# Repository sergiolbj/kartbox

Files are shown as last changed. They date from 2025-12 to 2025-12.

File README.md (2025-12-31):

# 🏎️ KartBox - Telemetria Avançada para Karting (ESP32)

O **KartBox** é um sistema de telemetria e dashboard para Karts de competição, desenvolvido com **ESP32** (ESP-IDF) e **LVGL v9**. Ele oferece monitoramento em tempo real de tempos de volta, velocidade, delta (gap) e registro de dados em cartão SD para análise posterior.






## 📸 Screenshots

*(Espaço reservado para você colocar uma foto ou print da tela do seu projeto)*

## 🚀 Funcionalidades Principais

### 🏁 Dashboard de Corrida (Aba Race)
- **Velocidade em Tempo Real:** Leitura de GPS de alta precisão.
- **Lap Timer:** Tempo da volta atual, última volta e **Best Lap**.
- **Live Delta:** Mostra a diferença de tempo para a melhor volta em tempo real (Verde = Mais rápido, Vermelho = Mais lento).
- **Modos de Corrida:** Alternância entre *Qualy* (Classificação) e *Race* (Corrida).

### 📊 Análise de Dados (Aba Voltas)
- **Histórico de Sessões:** Lista corridas salvas no SD pelo nome do arquivo (ex: `SESSION_001.LOG`).
- **Gráfico Dinâmico:**
  - Eixo Y (Velocidade) escala automaticamente conforme a maior velocidade atingida.
  - Eixo X exibe o número das voltas.
- **Botão Refresh:** Recarrega os dados do cartão SD sem reiniciar o sistema.

### 💾 Datalogger Robusto (SD Card)
- **Arquitetura Anti-Crash:** O salvamento de arquivos pesados roda em uma **Task FreeRTOS dedicada**, isolada da interface gráfica (UI), prevenindo erros de *Spinlock* e travamentos visuais.
- **CSV Format:** Dados exportáveis (Lat, Lon, Speed, Timestamp) compatíveis com softwares de análise.
- **Detecção Inteligente:** Identifica arquivos automaticamente na inicialização.

### 🛰️ Monitoramento de Saúde do GPS
Diagnóstico visual avançado no topo da tela:
- 🔴 **GPS: ERRO HW:** Módulo desconectado ou falha de comunicação (RX/TX).
- 🟡 **SATS: 0 BUSCA...:** Hardware OK, aguardando sinal de satélites.
- 🟢 **SATS: X FIX:** Sinal travado e pronto para uso.

## 🛠️ Hardware Utilizado

- **MCU:** ESP32-P4 (Function EV Board) ou compatível (ESP32-S3/WROOM).
- **Display:** LCD com interface RGB/SPI (Driver ST7701/EK79007).
- **GPS:** Módulo NMEA (ex: BN-880, NEO-6M) via UART.
- **Armazenamento:** Módulo MicroSD (SDMMC ou SPI).
- **IMU:** (Opcional) MPU6050/9250 para dados de força G.

## 📂 Estrutura do Projeto

```text
/main
├── main.c              # Ponto de entrada e setup do hardware
├── ui_kartbox.c        # Lógica da Interface (LVGL), Gráficos e Eventos
├── telemetry_gps.c     # Parser NMEA e lógica de Delta
├── telemetry_sd.c      # Gerenciamento de Arquivos e Logs
├── telemetry_mpu.c     # Leitura de sensores inerciais
└── ...

🎮 Como Usar
Inicialização: Ao ligar, aguarde o status do GPS ficar VERDE (FIX).

Marcar Linha de Chegada: Na primeira volta, pressione "MARCAR" onde deseja definir a linha de chegada/largada.

Correr: O sistema detectará as voltas automaticamente via coordenadas GPS.

Salvar: Ao fim da corrida, segure o botão "RESET" por 2 segundos.

Nota: O salvamento ocorre em background. Uma barra de progresso indicará a conclusão.

Revisar: Vá até a aba "VOLTAS", selecione a corrida e clique no botão de Refresh 🔄 para ver o gráfico de desempenho.

🤝 Contribuição
Contribuições são bem-vindas! Sinta-se à vontade para abrir Issues ou enviar Pull Requests.

📜 Licença
Este projeto está sob a licença MIT. Sinta-se livre para usar e modificar.

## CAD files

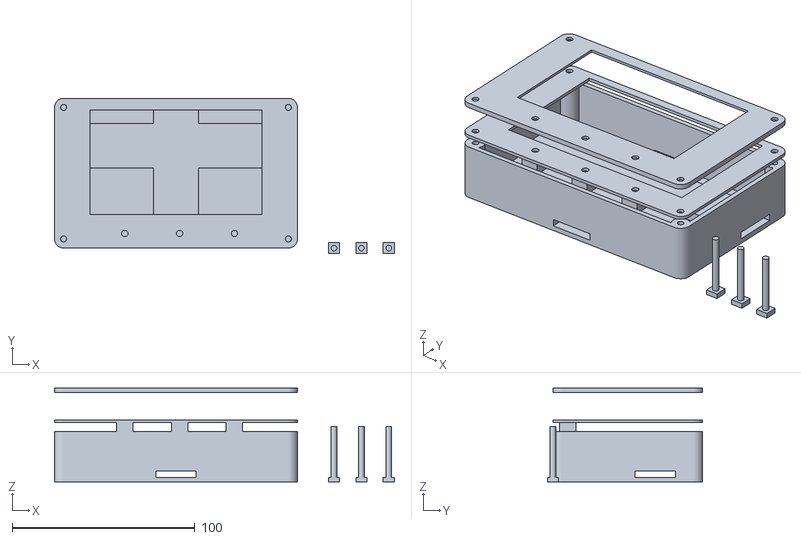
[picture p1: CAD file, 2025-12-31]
Case/kartbox_case_v4.stl
186.1 x 85.1 x 51.4

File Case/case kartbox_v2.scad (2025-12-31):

// ==========================================
//   KARTBOX PRO - BOTÕES COM ENCAIXE QUADRADO
// ==========================================

// --- 1. DIMENSÕES TÉCNICAS (LCD 4.3") ---
tela_l = 104; 
tela_c = 62.0;
margem_parafuso = 12.0;      
espaco_botoes = 15.0;       
gap_topo_tela = 2.0;        
deslocamento_geral_x = 2.0; 
distancia_entre_botoes = 30.0; 

// AJUSTE: Offset exclusivo para a peça do meio (suporte da tela)
offset_x_tampa_meio = 0.0; 

// AJUSTE: Offset vertical dos botões
offset_y_botoes = -2.0; 

// --- 2. CONFIGURAÇÃO DO BERÇO E DO PINO (ANTI-ROTAÇÃO) ---
dim_switch = 6.6;           // Encaixe interno do berço
parede_berco = 1.2;         
altura_parede_berco = 8.0;  // Profundidade do guia do botão

// Configuração do Botão (Pino)
dim_base_pino = dim_switch - 0.4; // Folga de 0.2mm de cada lado para deslizar
altura_base_pino = 2.5;           // Altura da parte quadrada que impede a rotação

// --- 3. CONFIGURAÇÃO DA MOLDURA SUPERIOR (A CASCA) ---
espessura_teto_moldura = 1.2;   
espessura_parede_moldura = 2; 
altura_interna_moldura = 1.2;   

// --- 4. AJUSTE DO VISOR (MOLDURA SUPERIOR) ---
moldura_janela_l = 94.0;    
moldura_janela_c = 57.0;    
moldura_h_offset = 0.0;     
moldura_v_offset = 6.5;     

// --- 5. ESTRUTURA DA BASE E TAMPA DO MEIO ---
espessura_tampa_meio = 1.5;      
altura_interna_base = 25.0; 
espessura_parede_caixa = 2.5;     
altura_strap = 3.5;         
parede_blindagem = 1.2;     

// --- 6. HARDWARE E CINTAS ---
btn_furo_diam = 3.5;        
diam_furo_m3 = 3.4;         
diam_insercao_m3 = 4.0;     
prof_insercao_m3 = 6.0;     
pos_strap_horizontal = 15;   
largura_strap = 22.0;       

// ==========================================
//   CÁLCULOS AUTOMÁTICOS
// ==========================================
largura = tela_l + (espessura_parede_caixa * 2) + (margem_parafuso * 2);
comprimento = tela_c + espaco_botoes + (espessura_parede_caixa * 2); 
altura_total_base = altura_interna_base + espessura_parede_caixa;
espessura_total_moldura = altura_interna_moldura + espessura_teto_moldura;
raio_canto = 5;
$fn = 60;

pos_x_parafuso = [raio_canto, largura - raio_canto];
pos_y_parafuso = [raio_canto, comprimento - raio_canto];

cy_strap = (comprimento/2) + pos_strap_horizontal;
cx_strap = largura/2; 

pos_y_botoes_base = espessura_parede_caixa + (espaco_botoes/2) + offset_y_botoes;

// ==========================================
//   MÓDULOS
// ==========================================

module base() {
    difference() {
        union() {
            difference() {
                hull() {
                    for(x=pos_x_parafuso, y=pos_y_parafuso) translate([x, y, 0]) cylinder(h=altura_total_base, r=raio_canto);
                }
                translate([espessura_parede_caixa, espessura_parede_caixa, espessura_parede_caixa])
                hull() {
                    ri = max(0.1, raio_canto - espessura_parede_caixa);
                    for(x=[ri, largura-espessura_parede_caixa*2-ri], y=[ri, comprimento-espessura_parede_caixa*2-ri])
                        translate([x, y, 0]) cylinder(h=altura_interna_base + 1, r=ri);
                }
            }
            intersection() {
                translate([espessura_parede_caixa, espessura_parede_caixa, espessura_parede_caixa])
                    cube([largura-espessura_parede_caixa*2, comprimento-espessura_parede_caixa*2, altura_strap + parede_blindagem]);
                union() {
                    translate([0, cy_strap - (largura_strap/2 + parede_blindagem), espessura_parede_caixa]) 
                        cube([largura, largura_strap + (parede_blindagem * 2), altura_strap + parede_blindagem]);
                    translate([cx_strap - (largura_strap/2 + parede_blindagem), 0, espessura_parede_caixa]) 
                        cube([largura_strap + (parede_blindagem * 2), comprimento, altura_strap + parede_blindagem]);
                }
            }
        }
        translate([-1, cy_strap - largura_strap/2, espessura_parede_caixa]) cube([largura + 2, largura_strap, altura_strap]); 
        translate([cx_strap - largura_strap/2, -1, espessura_parede_caixa]) cube([largura_strap, comprimento + 2, altura_strap]);

        for(x=pos_x_parafuso, y=pos_y_parafuso)
            translate([x, y, altura_total_base - prof_insercao_m3 + 0.1]) cylinder(h=prof_insercao_m3 + 1, r=diam_insercao_m3/2);
    }
    for(x=pos_x_parafuso, y=pos_y_parafuso)
        translate([x, y, espessura_parede_caixa])
        difference() {
            cylinder(h=altura_interna_base, r=4.5);
            translate([0,0, -1]) cylinder(h=altura_interna_base + 2, r=1.6); 
        }
}

module tampa_intermediaria() {
    translate([0, 0, altura_total_base + 5]) 
    union() {
        difference() {
            hull() {
                for(x=pos_x_parafuso, y=pos_y_parafuso) translate([x, y, 0]) cylinder(h=espessura_tampa_meio, r=raio_canto);
            }
            // Recorte da tela
            translate([largura/2 - tela_l/2 + deslocamento_geral_x + offset_x_tampa_meio, comprimento - tela_c - espessura_parede_caixa - gap_topo_tela, -1])
                cube([tela_l, tela_c, espessura_tampa_meio + 2]);
            
            // Furos Botões
            for(i = [-1:1])
                translate([largura/2 + (i * distancia_entre_botoes) + deslocamento_geral_x, pos_y_botoes_base, -1])
                    cylinder(h=espessura_tampa_meio + 2, r=btn_furo_diam/2);
            
            for(x=pos_x_parafuso, y=pos_y_parafuso) translate([x, y, -1]) cylinder(h=espessura_tampa_meio + 2, r=diam_furo_m3/2);
        }

        // BERÇO DOS BOTÕES (Bosses quadrados)
        for(i = [-1:1]) {
            translate([largura/2 + (i * distancia_entre_botoes) + deslocamento_geral_x, pos_y_botoes_base, -altura_parede_berco])
            difference() {
                translate([-(dim_switch/2 + parede_berco), -(dim_switch/2 + parede_berco), 0])
                    cube([dim_switch + parede_berco*2, dim_switch + parede_berco*2, altura_parede_berco]);
                translate([-dim_switch/2, -dim_switch/2, -0.1])
                    cube([dim_switch, dim_switch, altura_parede_berco + 0.2]);
                translate([0, 0, -1]) cylinder(h=altura_parede_berco + 2, r=btn_furo_diam/2);
            }
        }
    }
}

module moldura_superior_furos_planos() {
    translate([0, 0, altura_total_base + 5 + espessura_tampa_meio + 15]) 
    difference() {
        hull() {
            for(x=pos_x_parafuso, y=pos_y_parafuso) translate([x, y, 0]) cylinder(h=espessura_total_moldura, r=raio_canto);
        }
        translate([0, 0, -0.1])
        hull() {
             for(x=pos_x_parafuso, y=pos_y_parafuso) 
                translate([x, y, 0]) 
                    cylinder(h=altura_interna_moldura + 0.1, r=raio_canto - espessura_parede_moldura);
        }
        translate([largura/2 - moldura_janela_l/2 + moldura_h_offset, 
                   comprimento - moldura_janela_c - moldura_v_offset, -1])
            cube([moldura_janela_l, moldura_janela_c, espessura_total_moldura + 2]);

        for(i = [-1:1])
            translate([largura/2 + (i * distancia_entre_botoes) + deslocamento_geral_x, pos_y_botoes_base, -1])
                cylinder(h=espessura_total_moldura + 2, r=btn_furo_diam/2);

        for(x=pos_x_parafuso, y=pos_y_parafuso) {
            translate([x, y, -1]) cylinder(h=espessura_total_moldura + 2, r=diam_furo_m3/2);
        }
    }
}

module pinos_botoes_anti_rotacao() {
    // Altura total calculada para atravessar o sanduíche
    altura_haste = altura_interna_base + espessura_tampa_meio + espessura_total_moldura + 1.5;
    
    translate([largura + 20, 0, 0])
    for(i = [0:2]) translate([i * 15, 0, 0]) {
        union() {
            // A BASE QUADRADA (O "sapato" que trava no berço)
            translate([-dim_base_pino/2, -dim_base_pino/2, 0])
                cube([dim_base_pino, dim_base_pino, altura_base_pino]);
            
            // A HASTE CILÍNDRICA (O atuador que sai da caixa)
            translate([0, 0, altura_base_pino])
                cylinder(h=altura_haste - altura_base_pino, r=(btn_furo_diam-0.4)/2);
        }
    }
}

// --- RENDER ---
base();
tampa_intermediaria();
moldura_superior_furos_planos();
pinos_botoes_anti_rotacao();

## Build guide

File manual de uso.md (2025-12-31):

# 📘 Manual do Usuário - KartBox V1.0

Bem-vindo ao **KartBox**, seu sistema de telemetria avançada para Karting. Este manual explica como operar o painel, registrar seus tempos de volta e analisar seu desempenho.

---

## 🚦 Guia Rápido (Para quem tem pressa)

1. **Ligue o KartBox:** Conecte a bateria/alimentação.
2. **Aguarde o GPS:** Olhe para o topo direito da tela.
   - 🟡 **AMARELO (BUSCA...):** Aguarde, está procurando satélites.
   - 🟢 **VERDE (FIX):** Pronto! Pode entrar na pista.
3. **Marque a Pista:** Na sua volta de aquecimento, ao passar pela linha de chegada, aperte o botão **"MARCAR"**.
4. **Pilote:** O sistema agora marcará as voltas automaticamente.
5. **Finalizar:** Pare o Kart. Segure o botão **"RESET" por 2 segundos** para salvar os dados no cartão SD.

---

## 🖥️ Conhecendo a Interface

O sistema possui 3 abas principais na parte inferior da tela.

### 1. Aba RACE (Painel de Corrida)
É a tela principal que você usa enquanto pilota.

* **Velocidade (Grande):** Sua velocidade atual em KM/H.
* **Tempo (Centro):** Cronômetro da volta atual.
* **Delta (Abaixo):** A diferença de tempo para sua melhor volta.
    * 🟢 **Verde (Negativo):** Você está mais rápido que sua melhor volta.
    * 🔴 **Vermelho (Positivo):** Você está mais lento.
* **Informações de Volta:** Mostra o número da volta atual e o tempo da **Best Lap** (Melhor volta).
* **Status do GPS (Topo Direito):** Indica a qualidade do sinal (veja a seção *Diagnóstico de GPS*).

**Botões da Tela:**
1.  **MODO:** Alterna entre *Race* (Corrida) e *Qualy* (Classificação). (Apenas muda o visual/cor da borda para referência).
2.  **MARCAR:** Define o ponto GPS atual como a linha de chegada/largada. **Obrigatório fazer uma vez por sessão.**
3.  **RESET:**
    * *Toque Curto:* Zera o cronômetro (se não estiver gravando).
    * *Segurar 2s:* **Salva a sessão** no cartão SD e encerra a gravação.

### 2. Aba VOLTAS (Análise)
Use esta tela quando estiver nos boxes para ver como foi seu desempenho.

* **Menu de Seleção:** Escolha a corrida que deseja ver (ex: `SESSION_001.LOG` ou Data/Hora).
* **Botão Refresh (🔄):** Recarrega os dados do cartão SD e atualiza o gráfico.
* **Gráfico de Barras:** Mostra a velocidade média ou máxima de cada volta. O gráfico ajusta a escala automaticamente (se você andou a 90km/h, a barra sobe até lá).
* **Lista:** Lista detalhada com o tempo de cada volta.

### 3. Aba CFG (Configurações)
* **Status do SD:** Mostra quanto espaço livre existe no cartão de memória.
* **Apagar Tudo:** Botão vermelho para limpar o cartão SD (Cuidado: apaga todas as corridas!).

---

## 📡 Diagnóstico de GPS (Luzes de Status)

No canto superior direito da tela RACE, o texto muda de cor para te avisar sobre a saúde do sistema:

| Cor | Mensagem | O que significa? | O que fazer? |
| :--- | :--- | :--- | :--- |
| 🔴 **Vermelho** | **GPS: ERRO HW** | O painel não está recebendo dados do módulo GPS. | Verifique se o fio do GPS soltou ou se o módulo está desligado. |
| 🟡 **Amarelo** | **SATS: 0 BUSCA...** | O hardware está OK, mas sem sinal de satélite. | Leve o Kart para céu aberto. Saia de garagens ou coberturas. |
| 🟢 **Verde** | **SATS: 8 FIX** | Sistema travado com satélites. Precisão OK. | Tudo pronto para correr! |

---

## 💾 Salvando seus Dados

O KartBox possui um sistema de proteção para não perder dados se a bateria cair, mas o ideal é salvar manualmente.

1.  Ao entrar nos boxes, pare o Kart.
2.  Pressione o botão **RESET** e **mantenha pressionado**.
3.  Uma barra vermelha aparecerá escrito **"A SALVAR..."**.
4.  Quando a barra encher, solte o botão. Uma mensagem "SESSÃO SALVA" aparecerá.
5.  Agora é seguro desligar o aparelho.

---

## ❓ Perguntas Frequentes (FAQ)

**P: Esqueci de apertar "MARCAR" na primeira volta.**
R: O sistema não saberá onde a volta fecha. Seus tempos não serão registrados corretamente. Aperte MARCAR assim que passar pela linha de chegada na próxima oportunidade.

**P: O gráfico na aba VOLTAS está vazio.**
R: Selecione a corrida no menu e aperte o botão **Refresh (🔄)** ao lado dele.

**P: O GPS fica sempre em "ERRO HW" vermelho.**
R: Isso indica problema físico. Verifique o cabo que conecta o módulo GPS à placa principal (Fios TX/RX).

**P: Como passo os dados para o computador?**
R: Retire o cartão MicroSD, coloque no PC e abra os arquivos `.CSV` no Excel ou em softwares de análise de telemetria como o *RaceRender* ou *MoTeC i2* (requer conversão).

---
*KartBox Team - Desenvolvido para Vencer.*

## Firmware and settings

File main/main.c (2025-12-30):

#include <stdio.h>
#include <stdbool.h>
#include <stdint.h>
#include "freertos/FreeRTOS.h"
#include "freertos/task.h"
#include "driver/gpio.h"
#include "esp_timer.h"
#include "bsp/esp-bsp.h"
#include "esp_lvgl_port.h"
#include "config.h"
#include "telemetry_gps.h"
#include "telemetry_sd.h"
#include "ui_kartbox.h"

bool recording_active = false; 
static uint32_t reset_press_start = 0;
static int last_mode_state = 1;
static int last_line_state = 1;

void end_race_session(void) {
    if (recording_active) {
        sd_stop_session();
        recording_active = false; 
        gps_reset_session();
        if (lvgl_port_lock(0)) {
            ui_clear_lap_list(); 
            ui_show_popup("SESSAO SALVA", 2500); 
            ui_hide_reset_progress();
            ui_update_sd_info(); // Atualiza o uso após salvar o arquivo
            lvgl_port_unlock();
        }
    }
}

void app_main(void) {
    bsp_display_start();
    if (lvgl_port_lock(0)) { 
        lv_display_set_rotation(lv_display_get_default(), LV_DISPLAY_ROTATION_270); 
        ui_init(); 
        lvgl_port_unlock(); 
    }
    bsp_display_backlight_on();

    gpio_config_t b_cfg = { 
        .pin_bit_mask = (1ULL<<BTN_MODE_PIN)|(1ULL<<BTN_SETLINE_PIN)|(1ULL<<BTN_RESET_PIN), 
        .mode = GPIO_MODE_INPUT, .pull_up_en = 1 
    };
    gpio_config(&b_cfg);

    gps_init();
    
    // Inicializa o SD e atualiza a interface se montado
    if (sd_init()) {
        if (lvgl_port_lock(0)) {
            ui_update_sd_info(); // MOSTRA O TAMANHO REAL DO CARTÃO AQUI
            ui_refresh_session_dropdown();
            lvgl_port_unlock();
        }
    }

    uint32_t last_ui = 0;

    while (1) {
        gps_data_t cur = gps_get_latest();
        gps_process_timing(&cur);
        
        if (recording_active) {
            sd_log_sample(cur, (mpu_data_t){0}, gps_get_mode(), gps_get_lap_count());
        }

        // --- BOTÃO MODO ---
        int mode_val = gpio_get_level(BTN_MODE_PIN);
        if (last_mode_state == 1 && mode_val == 0) {
            gps_toggle_mode();
            if (lvgl_port_lock(0)) { ui_show_mode_splash(gps_get_mode()); lvgl_port_unlock(); }
        }
        last_mode_state = mode_val;

        // --- BOTÃO LINHA ---
        int line_val = gpio_get_level(BTN_SETLINE_PIN);
        if (last_line_state == 1 && line_val == 0) {
            if (gps_set_finish_line()) {
                recording_active = true;
                if (lvgl_port_lock(0)) { ui_show_popup("GRAVANDO...", 1500); lvgl_port_unlock(); }
            } else {
                if (lvgl_port_lock(0)) { ui_show_popup("SEM SINAL GPS", 1500); lvgl_port_unlock(); }
            }
        }
        last_line_state = line_val;

        // --- BOTÃO RESET ---
        if (gpio_get_level(BTN_RESET_PIN) == 0) {
            if (reset_press_start == 0) reset_press_start = esp_timer_get_time() / 1000;
            uint32_t held = (esp_timer_get_time() / 1000) - reset_press_start;
            if (recording_active && lvgl_port_lock(0)) { ui_update_reset_progress((held * 100) / 2000); lvgl_port_unlock(); }
            if (held >= 2000) end_race_session();
        } else {
            if (reset_press_start != 0) {
                uint32_t held = (esp_timer_get_time() / 1000) - reset_press_start;
                if (held < 2000 && !recording_active) {
                    gps_reset_session();
                    if (lvgl_port_lock(0)) { ui_show_popup("ZERADO", 1000); lvgl_port_unlock(); }
                }
                if (lvgl_port_lock(0)) { ui_hide_reset_progress(); lvgl_port_unlock(); }
                reset_press_start = 0;
            }
        }

        uint32_t now = esp_timer_get_time() / 1000;
        if (now - last_ui >= UI_UPDATE_MS) {
            if (lvgl_port_lock(0)) {
                ui_update(cur, (mpu_data_t){0}, gps_get_current_time_ms(), gps_get_last_lap(), gps_get_best_lap(), gps_get_lap_count(), sd_get_current_session_id());
                lvgl_port_unlock();
            }
            last_ui = now;
        }
        vTaskDelay(pdMS_TO_TICKS(10)); 
    }
}

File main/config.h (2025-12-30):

#ifndef CONFIG_H
#define CONFIG_H

#include "driver/gpio.h"
#include "driver/uart.h"

// ========== PINOS ESP32-P4 (JC4880P443C) ==========
// SD Card (Barramento SD1 Nativo)
#define SD_CMD_PIN          44  
#define SD_CLK_PIN          43  
#define SD_D0_PIN           39  
#define SD_PWR_EN_PIN       45  // P-MOSFET (0 = LIGADO)

// Botões Físicos
#define BTN_MODE_PIN        GPIO_NUM_33
#define BTN_SETLINE_PIN     GPIO_NUM_31
#define BTN_RESET_PIN       GPIO_NUM_30

// GPS (UART1)
#define GPS_UART_NUM        UART_NUM_1
#define GPS_TX_PIN          52
#define GPS_RX_PIN          51
#define GPS_BAUD_RATE       115200 

// MPU-6050 (I2C0)
#define MPU_I2C_NUM         I2C_NUM_0
#define MPU_SDA_PIN         7   
#define MPU_SCL_PIN         8   
#define MPU_I2C_FREQ        400000 // Frequência do barramento I2C

// ========== CONSTANTES DE TELEMETRIA ==========
#define MAX_LAPS            100    // Limite de voltas na memória
#define UI_UPDATE_MS        100 
#define GATE_RADIUS_M       12.0   // Raio do portão virtual (metros)
#define MIN_LAP_TIME_MS     20000  // Tempo mínimo de volta (evita triggers falsos)

#endif

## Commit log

2025-12-30 Upload inicial KartBox
    [partitions.csv]
2025-12-31 Docs: Adicionado Manual de Uso do projeto
2025-12-31 Script: Adicionado o analisador de log em python
2025-12-31 Add Case do projeto
    [case kartbox_v2.scad]
2026-01-14 melhorias no script de datalogger
